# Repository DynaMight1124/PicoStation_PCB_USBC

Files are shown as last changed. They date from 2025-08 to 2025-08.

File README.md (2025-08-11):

# PicoStation PCB remixed with some improvements!

Heres a remix of the original PCB with some admendments and improvements.
* Added USBC port for easy updates!
* Changed MicroSD slot for a surface mounted design with spring mechanism
* Adjusted spacing for the mounts as they were not correct originally
* Removed debug port - dont think its needed
* Created a 3D Printed cover as well as mounts

As for ordering the PCB's, stock 1.6mm settings are fine. 

You can also find gerbers for QSB's here: https://github.com/WakaMax/PS1_Picostation_QSB (I would suggest these are ordered at 0.8mm as would match the size of other QSB style boards)




| PART | LINK |
|---|---|
| Pico | https://www.aliexpress.com/item/1005007393927221.html  |
| USBC Connectors - 10mm | https://www.aliexpress.com/item/1005007522269561.html |
| 0805 10uF capacitors | https://www.aliexpress.com/item/32964553793.html |
| 0805 10k resisors | https://www.aliexpress.com/item/1005005600798857.html |
| 0805 4.7k resisors | https://www.aliexpress.com/item/1005005600798857.html |
| 0805 LEDs | https://www.aliexpress.com/item/1005007252088951.html Whatever colour you prefer! |
| SOD-123 1N5819 | https://www.aliexpress.com/item/1005005707644429.html |
| MicroSD Slots | https://www.aliexpress.com/item/1005001331379046.html |
| 20pin 1mm pitch FFC Sockets | https://www.aliexpress.com/item/10000348360254.html |
| 20pin 1mm pitch FFC Cables | https://www.aliexpress.com/item/1005007561337665.html Reversed direction, 200mm long |
| TO-252 7505 | https://www.aliexpress.com/item/1005005872653015.html |

* Soldering the Pico requires extra attention as the USBC port uses test pads on the bottom of the Pico which are fairly close to each other, these need to be accurately lined up and board completely flat else may cause bridges, it might also help if you *very* lightly tinned the test pads on the bottom the Pico as should help attract the solder from the throughhole. I would recommend soldering two pads on the Pico at opposite ends to anchor when you're happy with the placement then flood filling the underside holes ensuring theres no bridges between them before solding the rest of the Pico pins, its way easier to attempt to desolder at this stage if theres a bridge than after all Pico pins have been soldered. If USBC port doesnt work when assembled, apply additional flux & heat and/or solder to the holes as likely didnt attach properly.

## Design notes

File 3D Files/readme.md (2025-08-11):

STL's for the PicoStation. The base goes under the PicoStation between the PicoStation and the PS1 shield and the Shim goes on the CD drive mount closest to the front of the console to ensure everything is level and secure.



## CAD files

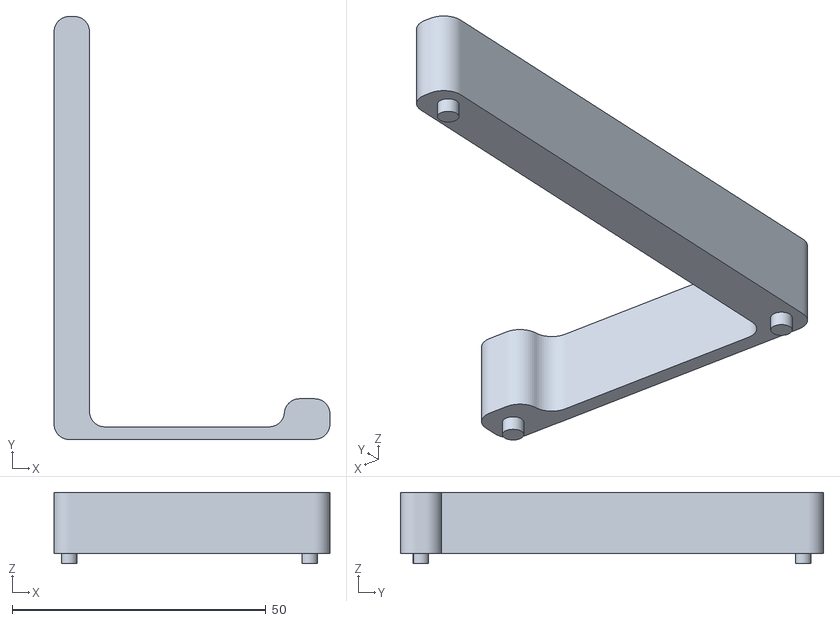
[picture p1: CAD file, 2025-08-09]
3D Files/PicoStation PCB Base.stl
54.4 x 83.4 x 14.0

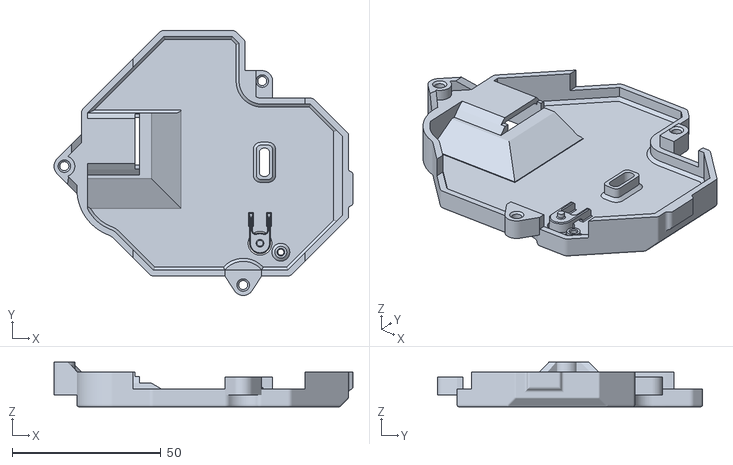
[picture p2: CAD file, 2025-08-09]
3D Files/PicoStation ODE Cover V2.stl
100.5 x 89.1 x 15.1

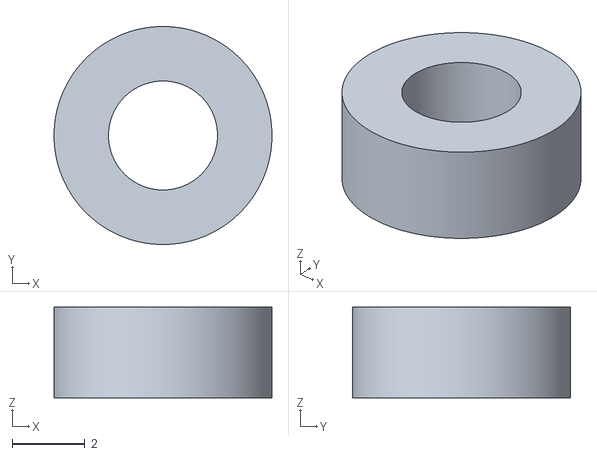
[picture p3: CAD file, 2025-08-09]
3D Files/Shim.stl
6.00 x 6.00 x 2.50
